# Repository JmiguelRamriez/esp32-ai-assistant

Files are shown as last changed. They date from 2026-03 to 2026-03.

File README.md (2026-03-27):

# Asistente Inteligente IA con ESP32 🤖

Un asistente de voz autónomo basado en hardware ESP32 que utiliza la potencia de la nube (Flask + Groq) para mantener conversaciones fluidas. "Luna" es capaz de escuchar tus peticiones, procesar transcripciones ultrarrápidas, generar inteligencia conversacional con Llama-3.1 y responder con voz de forma directa por sus altavoces, a la vez que muestra animaciones en su pantalla OLED interactiva.

---

## Características Principales

1. **Interacción Dual**:
   - **Wake Word ("Luna")**: Escucha continua optimizada. Puedes llamarla por su nombre, el ESP32 transmite al backend para confirmar la detección y despierta de inmediato.
   - **Botón Físico**: Interacción clásica manteniendo presionado un pulsador (Pin 14) para dictar o grabar peticiones manualmente.
2. **Sistema VAD (Voice Activity Detection)**:
   - Implementado nativamente en MicroPython local. La grabación para la detección de la palabra de activación se dispara solo si la amplitud del micrófono supera un umbral dinámico (se evitan grabaciones en silencio), ahorrando batería y ancho de banda al servidor.
3. **Gestión de Red y Memoria Avanzada**:
   - **Sockets HTTP Manuales y Chunking**: Para evitar los severos límites de RAM en MicroPython al enviar archivos pesados (WAVs completos), el cliente usa sockets HTTP puros y _chunking_ (envío múltiple fragmentado del búfer).
   - **Auto-Estabilización WiFi**: El controlador de red local cuenta con reinicio lógico forzoso, sorteando con solidez los conocidos bloqueos de conexión fantasma en los ESP32.
4. **Reproducción Estabilizada por Hardware DAC**:
   - **Audio Puro**: El backend construye respuestas TTS de pydub a formato PCM 8000Hz Mono, de 8-bits unsigned. Formato nativo para el DAC del ESP32 (Pines 25 y 26).
   - **Compensación de Latencia**: El bucle de lectura/escritura en MicroPython tiene retrasos medidos y deducidos del Sample Rate original usando compensación en microsegundos, asegurando máxima sincronía y evitando saltos de audio.
5. **Interfaz Visual Viva (Pantalla SH1106)**:
   - Pantalla interactiva que reacciona según cada fase del pipeline (dormido/Zzzz, sorprendido al escuchar, cargando mientras procesa la red, hablando al transcribir, u ojos tristes si surge algún fallo).
   - Reloj local mantenido en segundo plano gracias a sincronización remota por NTP (Network Time Protocol).
6. **Backend Potenciado por IA de Groq**:
   - `/transcribir` y `/despertar` delegan el audio recogido hacia **Whisper Large V3 Turbo** de Groq.
   - `/preguntar` redirige el texto al modelo **Llama-3.1-8B-Instant**, incorporando el archivo `historial.json` para gestionar un contexto temporal configurable.
   - "Miguel" es el pre-prompt. Una personalidad de universitario, 20 años que es amable y precisa.

---

## Arquitectura del Sistema

El ecosistema consiste en un modelo "Cliente Front" (ESP32) y un "Servidor de Carga" (Python Flask):

```text
Asistente/
├── firmware/                 # CÓDIGO MICROPYTHON PARA EL ESP32 (SUBIR A LA PLACA)
│   ├── main.py               # Máquina de estados: Ciclo de Pooling de botones/micrófono y manejo visual UI.
│   ├── config.py             # Archivo para inyección de credenciales WiFi y dirección IP/Host.
│   ├── cliente.py            # Orquestador de peticiones: streaming de audios usando *usocket* crudo.
│   ├── grabar.py             # Control I2S (RX) del micrófono, lectura en bloques y aplicación de algoritmo VAD.
│   ├── reproductor.py        # Salida analógica. Lee un .wav y lo transfiere a los pines DAC ciclo por ciclo.
│   ├── pantalla.py           # Gestor gráfico (I2C): rendering frame-a-frame de las expresiones faciales.
│   ├── sh1106.py             # Controlador de hardware display monocromo, primitivas gráficas nativas.
│   └── wifi.py               # Boot de red confiable (Auto-reconexión profunda de interfaces STA).
│
├── firmware/servidor/        # BACKEND FLASK (En tu computadora local o la nube (PaaS / Render))
│   ├── servidor.py           # Expone API: /transcribir, /preguntar, /hablar, /despertar, /reset.
│   ├── requirements.txt      # Paquetes a instalar con pip (flask, requests, gtts, pydub, python-dotenv).
│   └── (historial.json)      # Fichero de base de datos auto-regenerado con memoria de largo plazo.
│
└── hardware/                 # RECURSOS FÍSICOS
    └── Asistente.kicad_pro   # Archivos de diagramas, ruteos (PCB layouts) provistos en formato KiCAD.
```

---

## Entradas y Salidas de Hardware (Diagrama Lógico Base)

- **Placa Principal**: Microcontrolador ESP32 (Se prefiere modelo clásico ESP-WROOM-32 estándar para aprovechar los 2 pines DAC).
- **Entrada de Audio (Micrófono I2S como INMP441)**:
  - SCK -> Pin 32
  - WS -> Pin 27
  - SD -> Pin 33
- **Salida de Pantalla (Pantalla OLED 1.3" I2C)**:
  - SCL -> Pin 22
  - SDA -> Pin 21
- **Salida de Audio Principal (DAC x2)**:
  - Canal L (Izquierdo) -> Pin 25 a la entrada analógica del circuito amplificador (Ej: PAM8403 / LM386).
  - Canal R (Derecho) -> Pin 26 a la entrada del ampli (o bocina / audífonos si se está derivando).
- **Control**:
  - Un pulsador general unido a un Pin de señal en Pull-Up conectado directo a -> Pin 14.

### Esquemático y Diseño PCB

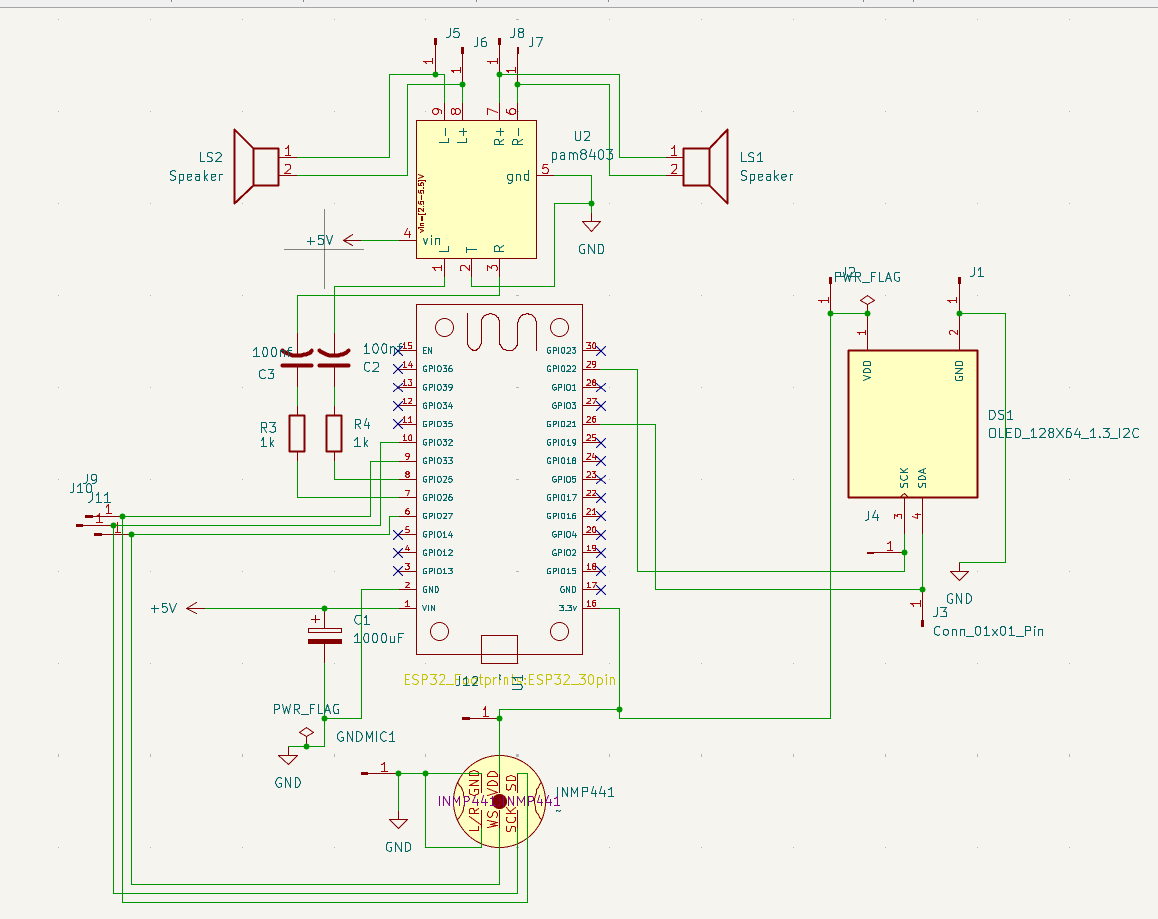
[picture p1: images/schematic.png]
Esquemático

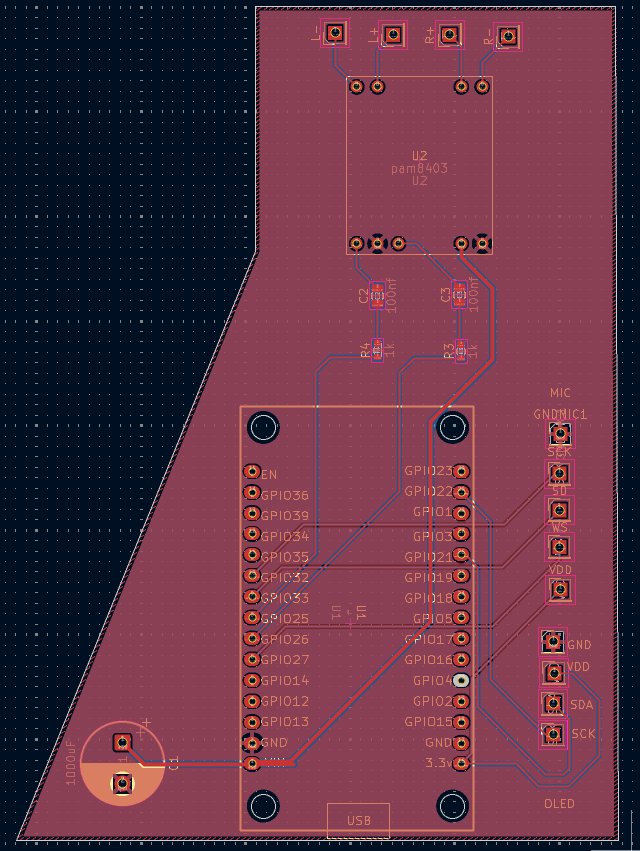
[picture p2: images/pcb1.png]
PCB Top

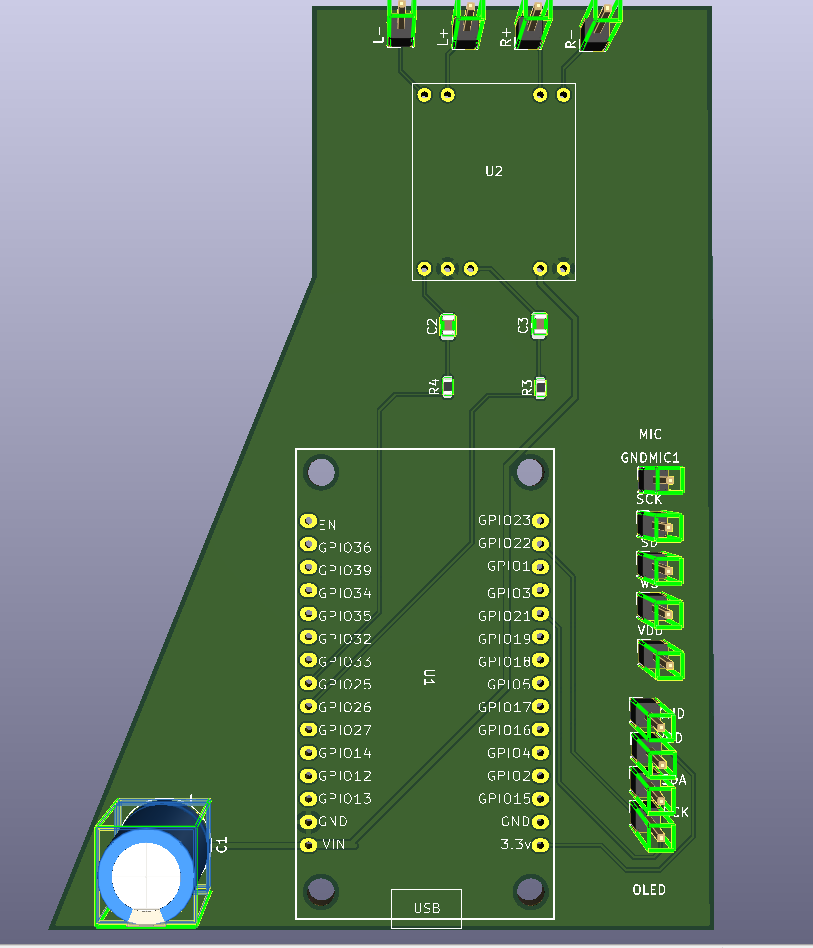
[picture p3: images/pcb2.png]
PCB Bottom


---

## Instalación y Despliegue

### 1. Levantar el Backend / Cerebro en Flask

Es indispensable correr este código de la carpeta en algún entorno de gran capacidad de procesamiento (Tu PC, o Render.com). Se requiere tener **FFmpeg** instalado a nivel sistema operativo para que la librería PyDub trabaje adecuadamente los archivos de sonido Gtts hacia `.wav` genérico.

1. Abre tu terminal y ve al sistema de archivos a `firmware/servidor`.
2. Instala las dependencias de control: `pip install -r requirements.txt`.
3. Crea a mano un fichero `.env` y dale permisos añadiendo tu API de procesamiento: `GROQ_API_KEY=tu_clave_de_api_aqui`.
4. Corre el cerebro local: `python servidor.py` (Dejalo encendido, escuchará en `http://0.0.0.0:5000`).

### 2. Flashear el Firmware MicroPython en el ESP32

1. Previamente graba el firmware _MicroPython_ (versión 1.19+ recomendada) en tu ESP32 con herramientas como Thonny IDE.
2. Mantén Abierto Thonny IDE. Modifica `firmware/config.py` e ingresa tu:
   - Red Inalámbrica `SSID` y de `PASSWORD` local de la habitación.
   - El hostname del servidor maestro y su puerto. Ejemplo: Para tu computadora bajo local WiFi usa la IP `SERVIDOR = "192.168.1.XX" y PUERTO = 5000`. Si usas dominio real SSL usa `PUERTO = 443`.
3. Arrastra a la memoria base del ESP32 `/` todos los ficheros .py de la carpeta principal del firmware.
4. Presiona RST/EN en la física placa del ESP (Hard-Reset). La placa reiniciará, te dirá que hace ping al NTP, y abrirá los ojos preparándose para funcionar.

### Ciclo de Uso:

1. **Atención**: Acercate a su micrófono y di "Luna" con voz clara (o si lo prefieres, pulsa y sosten tu botón durante 3 segundos al hablar).
2. **Sorpresa**: La pantallita de OLED abrirá los ojos grande y te indicará por serial "Escuchando...". Pídele que elabore algún tema académico o una definición rápida.
3. **Caché**: El modelo cambiará a "carita dudando a los lados" y en breves momentos, el generador LLaMA 3.1 descargará de un tazón el WAV procesado.
4. **Respuesta**: El ESP32 se enlazará localmente de hardware y su bocina hablará mientras simula de forma fluida y divertida ondas de palabras. ¡Listo!

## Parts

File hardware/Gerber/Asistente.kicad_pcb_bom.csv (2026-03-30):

Designator | Quantity | Value | Footprint | Package | MPN | DNP | Mount_Type | Description | Field5
C1 | 1 | 1000uF | CP_Radial_D10.0mm_P5.00mm |  |  |  | tht | Polarized capacitor | 16V
C2, C3 | 2 | 100nf | C_Disc_D5.0mm_W2.5mm_P5.00mm |  |  |  | tht | capacitor, US symbol
GND, GNDMIC1, L+, L-, R+, R-, SCK, SCK, SD, SDA, VDD, VDD, WS | 13 | Conn_01x01_Pin | PinHeader_1x01_P2.54mm_Vertical |  |  |  | tht | Generic connector, single row, 01x01, script generated
R3, R4 | 2 | 1k | R_Axial_DIN0207_L6.3mm_D2.5mm_P10.16mm_Horizontal |  |  |  | tht | Resistor
U1 | 1 | ~ | ESP32_30pin |  |  |  | tht
U2 | 1 | pam8403 | pam8403 |  |  |  | tht

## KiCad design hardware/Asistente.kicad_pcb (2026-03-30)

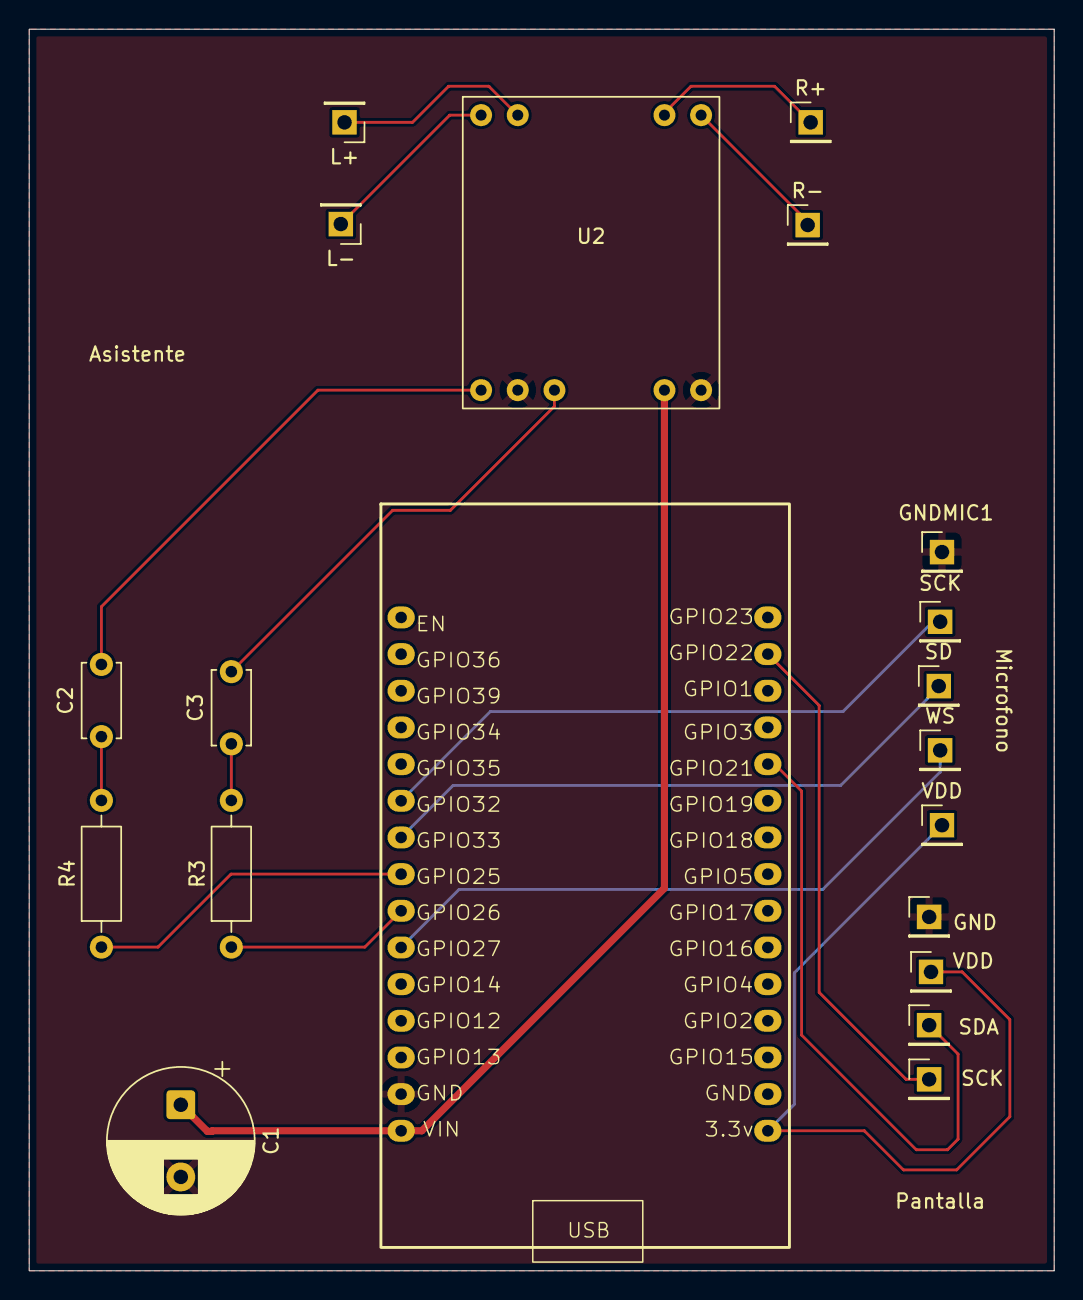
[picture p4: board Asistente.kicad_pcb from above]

Board: 2 copper layers, 71.0 x 86.0 mm, 20 parts (0 on the bottom side), 18 nets.

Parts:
C1: 1000uF; CP_Radial_D10.0mm_P5.00mm
C2, C3: 100nf; C_Disc_D5.0mm_W2.5mm_P5.00mm
GND: Conn_01x01_Pin; PinHeader_1x01_P2.54mm_Vertical
GNDMIC1: Conn_01x01_Pin; PinHeader_1x01_P2.54mm_Vertical
L+: Conn_01x01_Pin; PinHeader_1x01_P2.54mm_Vertical
L-: Conn_01x01_Pin; PinHeader_1x01_P2.54mm_Vertical
R3, R4: 1k; R_Axial_DIN0207_L6.3mm_D2.5mm_P10.16mm_Horizontal
R+: Conn_01x01_Pin; PinHeader_1x01_P2.54mm_Vertical
R-: Conn_01x01_Pin; PinHeader_1x01_P2.54mm_Vertical
SCK: Conn_01x01_Pin; PinHeader_1x01_P2.54mm_Vertical
SCK#2: Conn_01x01_Pin; PinHeader_1x01_P2.54mm_Vertical
SD: Conn_01x01_Pin; PinHeader_1x01_P2.54mm_Vertical
SDA: Conn_01x01_Pin; PinHeader_1x01_P2.54mm_Vertical
U1: ESP32_30pin
U2: pam8403
VDD: Conn_01x01_Pin; PinHeader_1x01_P2.54mm_Vertical
VDD#2: Conn_01x01_Pin; PinHeader_1x01_P2.54mm_Vertical
WS: Conn_01x01_Pin; PinHeader_1x01_P2.54mm_Vertical

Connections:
+5V: C1.1, U1.1 (VIN), U2.4 (vin)
GND: C1.2, GND.1, GNDMIC1.1, U1.2 (GND), U2.2 (T), U2.5 (gnd)
unnamed: C2.1, R4.2
unnamed: C3.1, R3.2
unnamed: SCK#2.1, U1.29 (GPIO22)
unnamed: SDA.1, U1.26 (GPIO21)
unnamed: U1.16 (3.3v), VDD.1, VDD#2.1
unnamed: L-.1, U2.9 (L-)
unnamed: L+.1, U2.8 (L+)
unnamed: R-.1, U2.6 (R-)
unnamed: R+.1, U2.7 (R+)
unnamed: SD.1, U1.9 (GPIO33)
unnamed: SCK.1, U1.10 (GPIO32)
unnamed: U1.6 (GPIO27), WS.1
unnamed: R4.1, U1.8 (GPIO25)
unnamed: R3.1, U1.7 (GPIO26)
unnamed: C2.2, U2.1 (L)
unnamed: C3.2, U2.3 (R)

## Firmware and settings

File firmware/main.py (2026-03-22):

import pantalla
import wifi
import cliente
import grabar
import gc
import os
import usocket
import ssl
import ujson
import config
from machine import Pin
import time

time.sleep(2)
wifi.conectar()
pantalla.iniciar()
pantalla.sincronizar_hora()

boton = Pin(14, Pin.IN, Pin.PULL_UP)

_t = 0
_ultimo_habla = time.time()  # Inicializar con tiempo real para evitar bug con NTP

pantalla.mostrar_reposo()
print("Esperando: botón o di 'Luna'...")


def verificar_wake_word():
    """Envía wake.wav al servidor y devuelve True si detectó 'Luna'."""
    try:
        tam = os.stat("wake.wav")[6]
        dominio = config.SERVIDOR.strip()
        addr = usocket.getaddrinfo(dominio, config.PUERTO, 0, usocket.SOCK_STREAM)[0][-1]
        sock = usocket.socket(usocket.AF_INET, usocket.SOCK_STREAM)
        sock.settimeout(15.0)
        sock.connect(addr)
        if config.PUERTO == 443:
            sock = ssl.wrap_socket(sock, server_hostname=dominio)

        req = (
            "POST /despertar HTTP/1.0\r\n"
            "Host: " + dominio + "\r\n"
            "Content-Type: audio/wav\r\n"
            "Content-Length: " + str(tam) + "\r\n"
            "Connection: close\r\n\r\n"
        ).encode()
        sock.write(req)

        with open("wake.wav", "rb") as f:
            buf = bytearray(1024)
            while True:
                n = f.readinto(buf)
                if n == 0:
                    break
                sock.write(buf[:n])

        resp = b""
        while True:
            chunk = sock.read(512)
            if not chunk:
                break
            resp += chunk
        sock.close()

        inicio = resp.find(b'{')
        fin = resp.rfind(b'}') + 1
        if inicio != -1 and fin > inicio:
            datos = ujson.loads(resp[inicio:fin])
            return datos.get('detectado', False)
    except Exception as e:
        print("Error wake word:", e)
    return False


def interactuar(modo_wake=False):
    global _ultimo_habla
    pantalla.mostrar_escuchando()
    gc.collect()
    try:
        if modo_wake:
            respuesta = cliente.escuchar_y_preguntar_wake()
        else:
            respuesta = cliente.escuchar_y_preguntar(boton)
        if respuesta:
            pantalla.mostrar_hablando()
            print("IA:", respuesta)
            cliente.hablar(respuesta)
        else:
            print("Sin respuesta.")
    except Exception as e:
        print("Error:", e)
    _ultimo_habla = time.time()


while True:
    # ── Prioridad 1: botón físico ─────────────────────────
    if boton.value() == 0:
        time.sleep(0.05)
        if boton.value() == 0:
            print("Botón presionado")
            interactuar()
            _t = 0
            pantalla.mostrar_reposo()

    # ── Prioridad 2: wake word ────────────────────────────
    elif time.time() - _ultimo_habla > 4:
        if grabar.grabar_wake_con_vad("wake.wav", umbral=300, duracion_ms=2500, timeout_ms=1500):
            gc.collect()
            if verificar_wake_word():
                print("¡Wake word 'Luna' detectado!")
                interactuar(modo_wake=True)
                _t = 0
                pantalla.mostrar_reposo()
        # Animar pantalla tanto si detectó voz como si no
        _t += 1
        pantalla.tick_reposo(_t)

    # ── Reposo: animar pantalla ──────────────────────────
    else:
        _t += 1
        pantalla.tick_reposo(_t)
        time.sleep(0.3)
        continue

    time.sleep(0.05)

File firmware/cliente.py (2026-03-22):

import usocket
import urequests
import ssl
import config
import grabar
import ujson
import os
import gc
import pantalla
import time  

def escuchar_y_preguntar_wake():
    """Graba 4 segundos fijos y consulta a la IA (sin botón)."""
    import grabar as _grabar

    class FakeBoton:
        def __init__(self): 
            self._fin = time.ticks_add(time.ticks_ms(), 4000)
        def value(self): 
            return 0 if time.ticks_diff(self._fin, time.ticks_ms()) > 0 else 1

    _grabar.grabar(FakeBoton(), "audio.wav")
    gc.collect()

    # A partir de aquí es igual que escuchar_y_preguntar
    pantalla.mostrar_pensando()
    dominio = config.SERVIDOR.strip()

    try:
        tam = os.stat("audio.wav")[6]
        addr = usocket.getaddrinfo(dominio, config.PUERTO, 0, usocket.SOCK_STREAM)[0][-1]
        sock = usocket.socket(usocket.AF_INET, usocket.SOCK_STREAM)
        sock.settimeout(60.0)
        sock.connect(addr)
        if config.PUERTO == 443:
            sock = ssl.wrap_socket(sock, server_hostname=dominio)

        request = (
            "POST /transcribir HTTP/1.0\r\n"
            "Host: " + dominio + "\r\n"
            "Content-Type: audio/wav\r\n"
            "Content-Length: " + str(tam) + "\r\n"
            "Connection: close\r\n\r\n"
        ).encode()
        sock.write(request)

        with open("audio.wav", "rb") as f:
            buf = bytearray(1024)
            while True:
                n = f.readinto(buf)
                if n == 0: break
                escrito = 0
                chunk = buf[:n]
                while escrito < n:
                    res = sock.write(chunk[escrito:])
                    if res: escrito += res

        respuesta_bytes = b""
        while True:
            try:
                chunk = sock.read(512)
                if not chunk: break
                respuesta_bytes += chunk
            except: break
        sock.close()

        respuesta = respuesta_bytes.decode('utf-8')
        gc.collect()
        inicio = respuesta.find('{')
        fin = respuesta.rfind('}') + 1
        if inicio != -1 and fin != -1:
            datos = ujson.loads(respuesta[inicio:fin])
            texto = datos.get('text', '')
            print("Escuché:", texto)
        else:
            return None
    except Exception as e:
        print("Error transcribiendo wake:", e)
        return None

    gc.collect()
    return preguntar(texto)


def escuchar_y_preguntar(boton):
    """
    Coordina el flujo completo: 
    1. Graba el audio.
    2. Envía el WAV al servidor por Sockets puros usando HTTP POST fragmentado 
       (Chunked / Multipart manual) para no agotar la RAM de MicroPython.
    3. Retorna la respuesta generada por la IA como texto.
    """
    # 1. Grabamos el audio desde el I2S(1)
    grabar.grabar(boton)
    gc.collect()

    pantalla.mostrar_pensando()
    print("Memoria libre:", gc.mem_free())
    
    dominio = config.SERVIDOR.strip()
    
    try:
        tam = os.stat("audio.wav")[6]
        print(f"Subiendo {tam} bytes por socket manual...")

        # 2. Configuración de conexión segura para la transcripción
        addr = usocket.getaddrinfo(dominio, config.PUERTO, 0, usocket.SOCK_STREAM)[0][-1]
        sock = usocket.socket(usocket.AF_INET, usocket.SOCK_STREAM)
        sock.settimeout(30.0) 
        
        sock.connect(addr)
        if config.PUERTO == 443:
            sock = ssl.wrap_socket(sock, server_hostname=dominio)
            
        # Petición HTTP/1.0 para cerrar la conexión al terminar
        request = (
            "POST /transcribir HTTP/1.0\r\n"
            "Host: " + dominio + "\r\n"
            "Content-Type: audio/wav\r\n"
            "Content-Length: " + str(tam) + "\r\n"
            "Connection: close\r\n\r\n"
        ).encode()
        
        sock.write(request)
        
        # Enviamos el archivo por pedazos (chunks) para no saturar la RAM
        with open("audio.wav", "rb") as f:
            buf = bytearray(1024)
            while True:
                n = f.readinto(buf)
                if n == 0:
                    break
                
                chunk = buf[:n]
                escrito = 0
                while escrito < n:
                    res = sock.write(chunk[escrito:])
                    if res:
                        escrito += res
                        
        print("Audio enviado, esperando respuesta...")
        
        # Leemos la respuesta del servidor
        respuesta_bytes = b""
        while True:
            try:
                chunk = sock.read(512)
                if not chunk:
                    break
                respuesta_bytes += chunk
            except:
                break
                
        sock.close()
        
        # Extraemos el texto de la transcripción
        respuesta = respuesta_bytes.decode('utf-8')
        gc.collect()
        
        inicio = respuesta.find('{')
        fin = respuesta.rfind('}') + 1
        
        if inicio != -1 and fin != -1:
            cuerpo = respuesta[inicio:fin]
            datos = ujson.loads(cuerpo)
            texto = datos.get('text', '')
            print("Escuché:", texto)
        else:
            print("Error: El servidor no devolvió un JSON.")
            return None
            
    except Exception as e:
        print("Error en socket manual:", e)
        return None

    gc.collect()

    # 3. Consultamos a la IA
    try:
        respuesta_ia = preguntar(texto)
    except Exception as e:
        print("Error en preguntar:", e)
        return None

    return respuesta_ia


def preguntar(texto):
    """
    Realiza una petición HTTP POST al endpoint /preguntar del backend.
    Envia la transcripción de voz para recibir la respuesta cognitiva del LLM.
    """
    gc.collect()

    # Limpiamos caracteres que rompen la estructura del JSON
    reemplazos = {
        '"': '', "'": '', '\n': ' ', '\r': ''
    }

    texto_limpio = texto
    for original, nuevo in reemplazos.items():
        texto_limpio = texto_limpio.replace(original, nuevo)
    texto_limpio = texto_limpio.strip()
    
    print("Texto limpio para IA:", repr(texto_limpio))

    try:
        url = "https://" + config.SERVIDOR.strip() + "/preguntar"
        
        # FIX: Codificamos a bytes UTF-8 para un conteo de longitud exacto
        body = ujson.dumps({"texto": texto_limpio}).encode('utf-8')
        
        resp = urequests.post(url, data=body, headers={"Content-Type": "application/json"}, timeout=30)
        datos = resp.json()
        resp.close()
        return datos['choices'][0]['message']['content']
    except Exception as e:
        print("Error al conectar con la IA:", e)
        return None
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

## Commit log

2026-03-18 functional voice assistant with ESP32, AI, and OLED animations
2026-03-19 fix: resolve hardware conflicts and JSON encoding issues
    [cliente.py, reproductor.py]
2026-03-19 docs: add comprehensive README with architecture, BOM and setup guide
2026-03-22 Fix wake word threshold in main.py, remove blocking loop in grabar.py, and add transcription tolerance in servidor.py
    [grabar.py, main.py]
2026-03-22 Fix module attribute error by forcing cliente.py sync and enable full wake word interaction
    [cliente.py, main.py, pantalla.py]
2026-03-23 hw: update PCB layout, add Gerber files and INMP441 footprint
    [Asistente-B_Cu.gbr, Asistente-B_Mask.gbr, Asistente-B_Paste.gbr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]
2026-03-27 feat: add external connectors for OLED, mic and speakers, update gerber files
    [Asistente-B_Cu.gbr, Asistente-B_Mask.gbr, Asistente-B_Paste.gbr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]
2026-03-27 docs: add schematic and PCB images
2026-03-27 docs: rewrite README to comprehensively document project architecture and hardware
    [Asistente.kicad_sch]
2026-03-30 Refactor and remove obsolete files
    [Asistente-B_Cu.gbr, Asistente-B_Mask.gbr, Asistente-B_Paste.gbr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]
